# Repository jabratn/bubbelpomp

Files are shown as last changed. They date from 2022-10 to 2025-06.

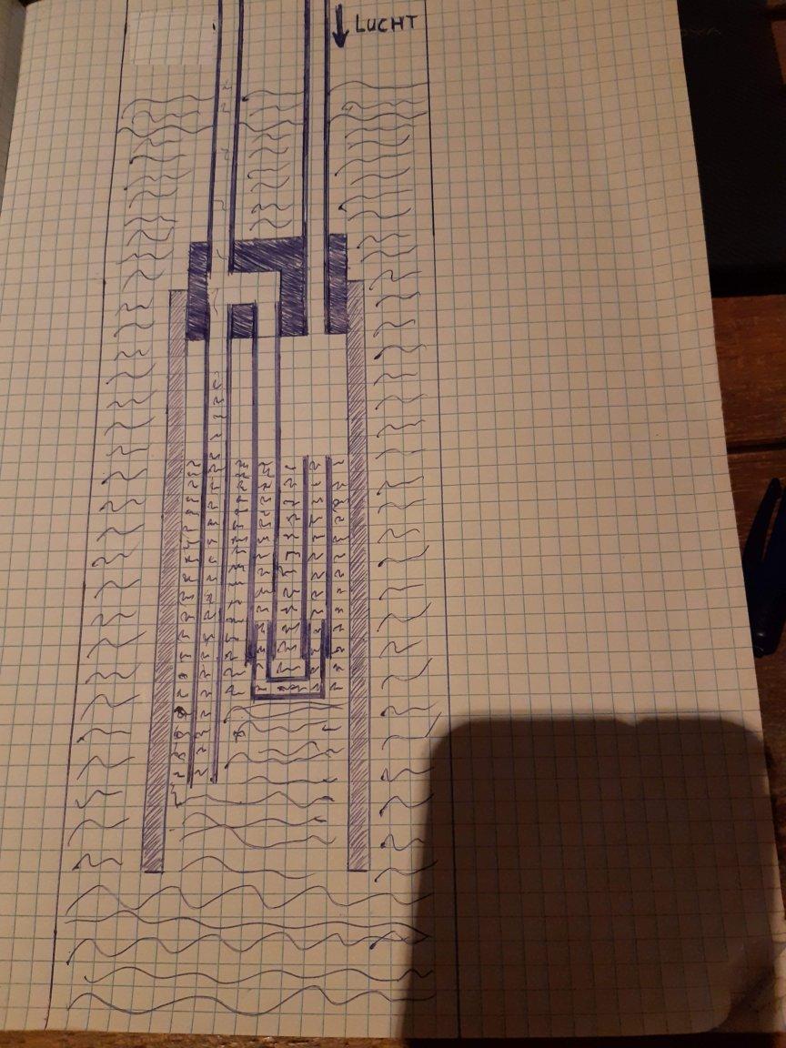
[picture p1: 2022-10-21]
introduction/pressure_building.jpg

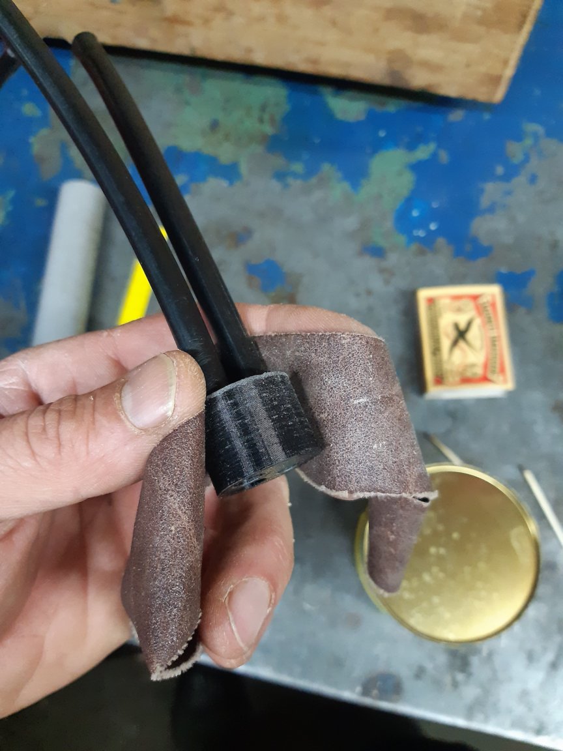
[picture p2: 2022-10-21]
construction/20220413_214501.jpg

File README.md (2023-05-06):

# Bubble pump

## Introduction
The bubble pump is a variant on the air-lift principle. When air is blown in a pipe or hose (under water) rising bubbles will force water upwards. Typically an air-lift pump will operate more efficiently when the inlet is placed deeper under water. The air will have to be more pressurised when the inlet is located further under the water surface. Therefore, when the bubbles rise up they will expand more and accelerate the rising water. This increases the pump capacity and efficiency. A variant of the air-lift pump operating at higher pressure is the geyser pump; here larger bubbles are created using a siphon principle. A chamber is filled with pressurized air, effectively displacing water until the deepest part of a siphon is exposed and the air chamber content is released suddenly in large bubble. Because of the high pressure, the bubble may carry a larger volume of water, again because it expands on its way up in the pump pipe or hose.

Our bubble pump is a poor man's version of the geyser pump. It is designed to be used with relatively small and cheap electrical air pumps that can be operated by simple and cheap solar panels. Typically the maximum air pressure difference these pumps can produce is 0.3\[bar\]. And therefore we cannot place our bubble pump much deeper than approximately 2 meters below the water surface. However, by design we make it easy to tune the size of the air bubble chamber such that you can optimize the pump for the depth of the water source (well or otherwise). The geyser effect will be negligible and the output not too high, but the main idea of this pump is that it may provide a small but steady stream of water. The supply can be either applied directly (e.g. irrigation, feeding life stock, etc) or stored for later use (e.g. a pond or storage tank).

The working of the bubble pump is based on the oscillating function of the siphon. By pumping air into the pump, water is pushed down until the level reaches the bottom of the siphon. Then a large bubble of air will be released, being pushed out by the rising water, until the level is equal to the top of the siphon. The air chamber above the siphon helps dampening the overshoot and smooth the transition into the next pump cycle.

## Materials
For the pump housing we use a PVC tube with a diameter of approx. 32\[mm\]. This should be small enough to fit in a fairly narrow borehole. *Note: these are outer diameters.* Length of this tube shall be at least 40\[cm\]. Wall thickness shall be less than 3\[mm\], otherwise the pump dimensions will not fit.

Both the pump and siphon are best 3D-printed in PETG because it is easier to produce an air tight pump plug. Measure the inner diameter of the PVC tube, and use it as basis in the parameterised model of the pump in **pump-par.FCStd**.

Pump and siphon are connected using PE tubing with outer diameter of 8\[mm\] and preferably a wall thickness of approx. 1\[mm\]. Measure the diameter and use it in the parameterised models of both the pump **pump-par.FCStd** and siphon **siphon-par.FCStd**. 

## Printing
Export the FreeCAD model in STL or AFM format and use your favourate rendering engine to create GCODE for your printer. Do not print supports, but when using a recent version of Cura it is a good idea to use the ``Make Overhang Printable`` option. This should result in a much nicer 'roof' of the cavity inside both the pump and the siphon.

## Construction
As mentioned above, the outer shell of the pump shall be made from a PVC tube of approx. 40\[cm\] long and minimal 32\[mm\] wide. Internally, for the siphon we will need a few pieces of 8\[mm\] PE tubing. Cut pieces of approx. 10, 20 and 30\[cm\]. The shorter ones for the siphon and the longest for the lifting tube. (See the accompanying photos.) The 10\[cm\] tube for the siphon height, the 20\[cm\] tube for the siphon plus air chamber height, and the 30\[cm\] tube for the water lifting part of the pump.

## Tips and tricks
Use a 12V rated air pump in combination with a 6V PV-panel. The pump will not run the fastest, but increase its life time (i.e. the rubber seals inside the pump will last a lot longer).
Print slightly warmer (approx. 5\[degC\]) then usually to help create an air tight PETG model.
Use 6\[mm\] silicon tubing to create the connection between the pump and the 8\[mm\] PE tube; a 1\[cm\] length piece of tube should be enough to fit on the pump and in the PE tube.

## Installation
The ideal depth for the pump is somewhere between 1 and 2\[m\] below the water surface. This type of small airpumps have a maximum rating of 0.3\[bar\], so placing the pump deeper is no use. And closer to the surface makes it more difficult for the oscillating process of the siphon to start up.

## Credits
The WOT in general, and Menno-Jan in particular.

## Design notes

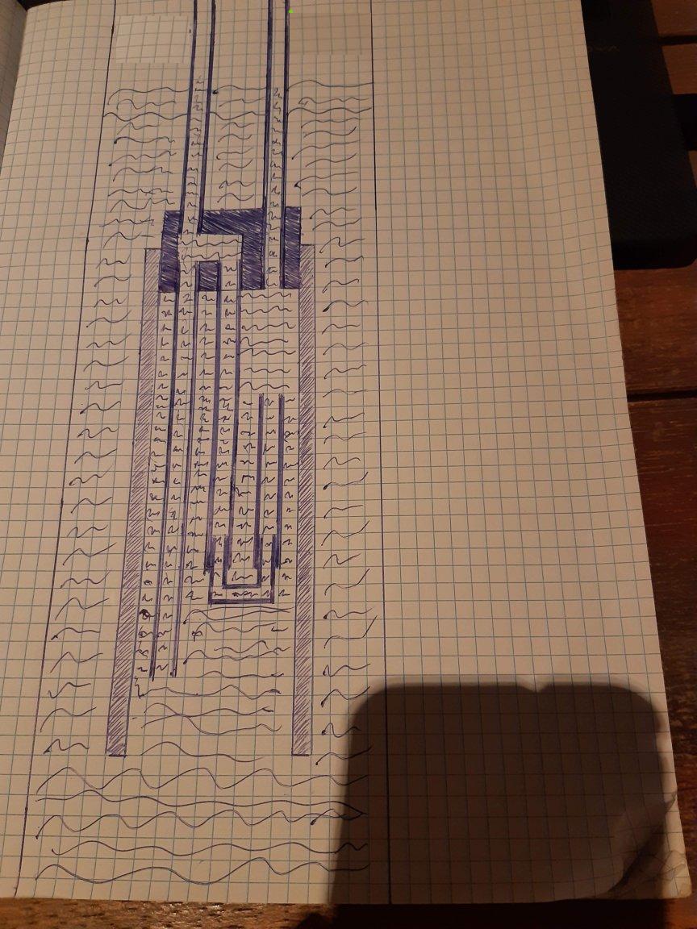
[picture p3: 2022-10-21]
introduction/idle_airpump_off.jpg

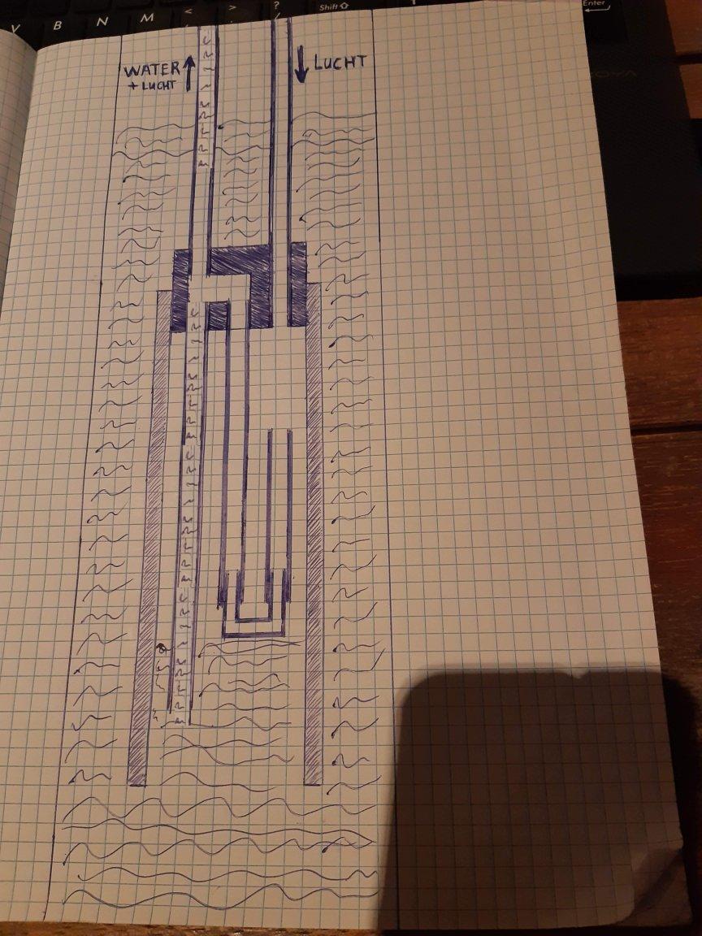
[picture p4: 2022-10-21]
introduction/release_via_siphon.jpg

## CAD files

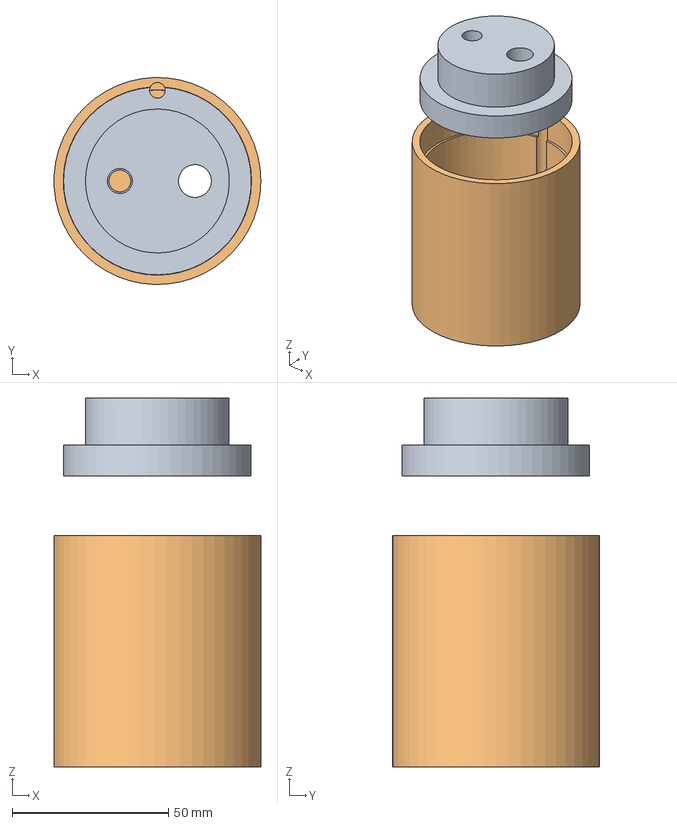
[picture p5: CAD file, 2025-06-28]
housing.FCStd
66.1 x 66.2 x 118.0 mm
base
cover

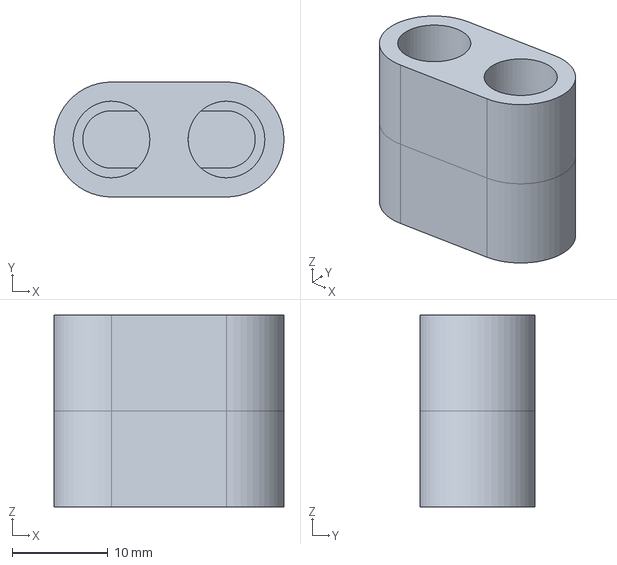
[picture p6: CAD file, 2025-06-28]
siphon.FCStd
24.0 x 12.0 x 20.0 mm

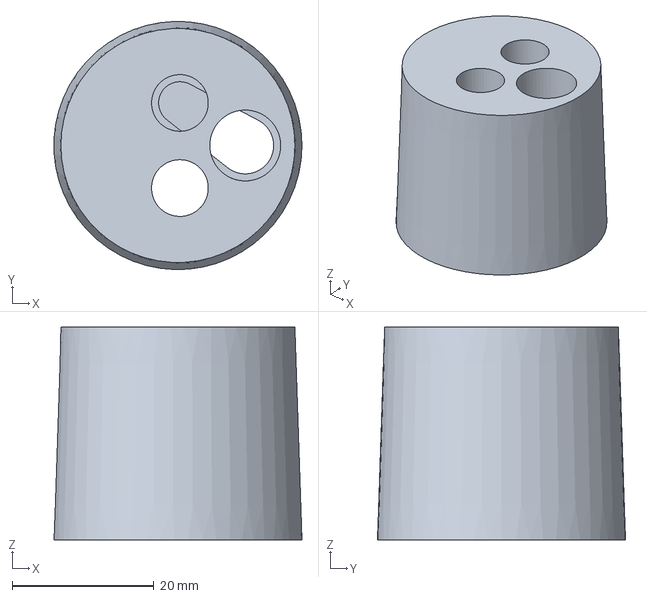
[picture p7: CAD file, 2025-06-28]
plug.FCStd
35.0 x 35.0 x 30.0 mm

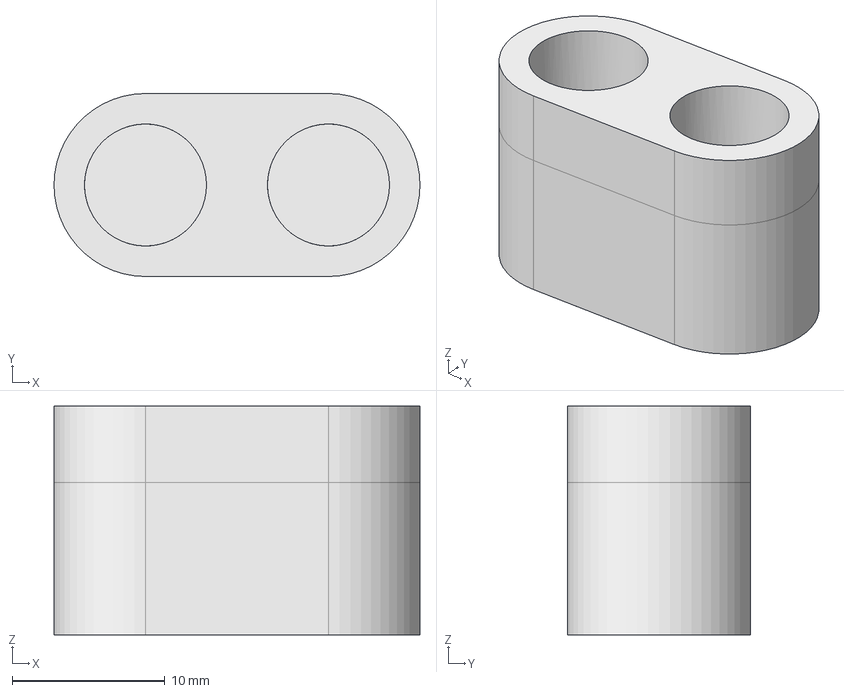
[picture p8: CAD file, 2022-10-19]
siphon-par.FCStd
24.0 x 12.0 x 15.0 mm

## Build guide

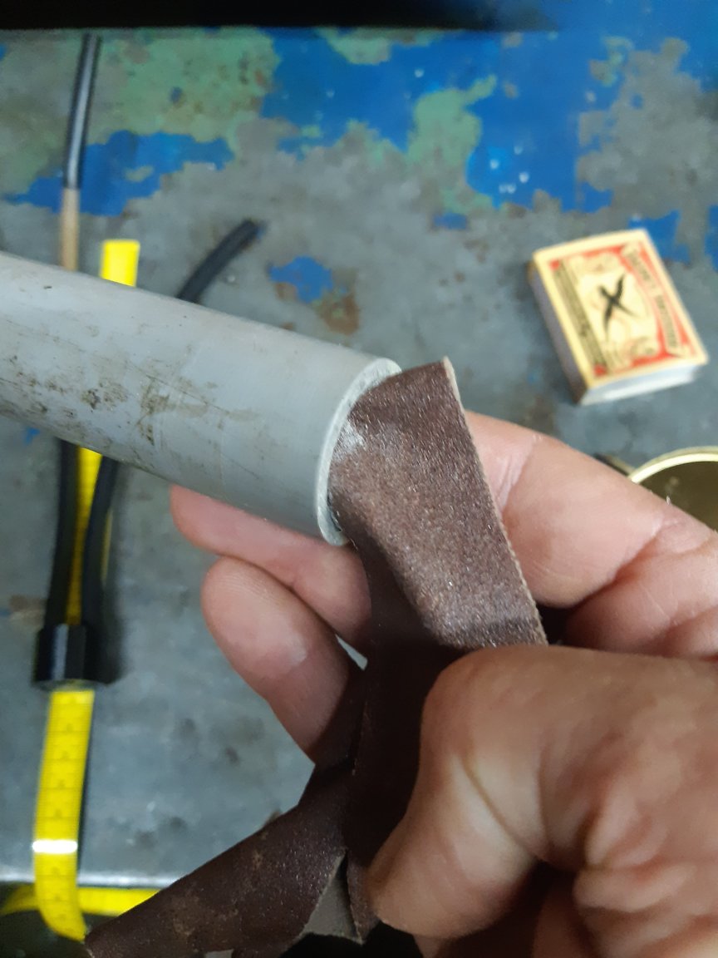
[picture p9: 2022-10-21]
construction/20220413_214350.jpg

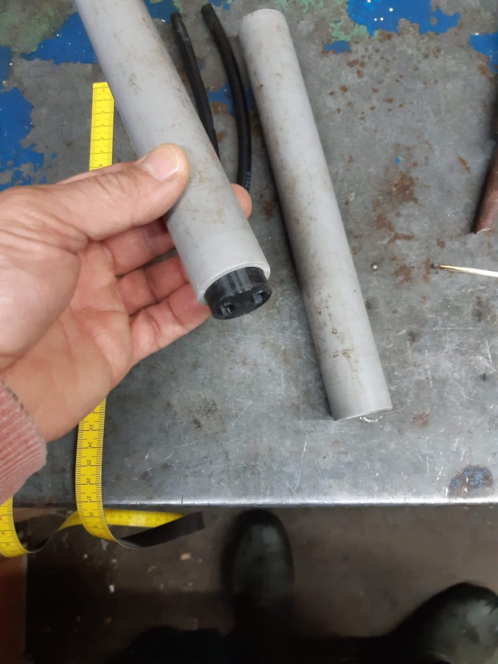
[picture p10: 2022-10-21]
construction/20220413_215520.jpg

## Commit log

2022-09-07 Add files via upload
    Initial version of pump and siphon.
    [pump.FCStd, siphon.FCStd]
2022-10-19 add parameterized FreeCAD models
    [pump-par.FCStd, siphon-par.FCStd]
2022-10-19 Update README.md
    add paragraph Materials and Printing
2022-10-19 remove older models with fixed dimensions
    [pump.FCStd, siphon.FCStd]
2023-03-06 add notes to spreadsheet
    [pump-par.FCStd]
2023-05-06 rename freecad files
    [plug.FCStd, siphon.FCStd]
2023-05-06 add more parameters to freecad models
    [plug.FCStd, siphon.FCStd]
2023-05-06 add housing model
    [housing.FCStd]
2025-06-28 FreeCAD v1 and change defaults for lift tube
    [housing.FCStd, plug.FCStd, siphon.FCStd]
